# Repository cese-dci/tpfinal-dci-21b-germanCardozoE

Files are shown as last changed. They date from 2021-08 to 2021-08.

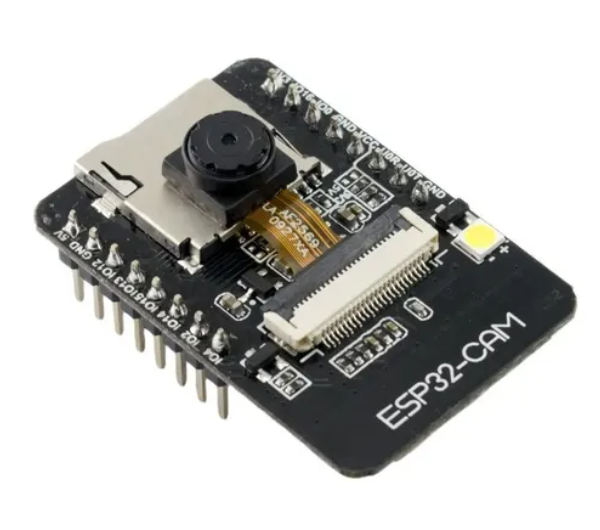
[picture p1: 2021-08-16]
doc/propuesta/esp32cam.png

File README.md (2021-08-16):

## Trabajo práctico final de la asignatura DCI ##
Este repositorio contiene el trabajo práctico final para la asignatura de Diseño de Circuitos Impresos de la carrera de posgrado de FIUBA.

* Autor: Cardozo Germán Eloy
* Título corto del trabajo:  ESP32-CAM
* Descripción:  El siguiente proyecto incluye tanto el circuito esquemático como el diseño del PCB realizado en kicad. A su vez se anexan diversas hojas de datos y bibliotecas utilizadas en su desarrollo.
ESP32-CAM es un módulo WiFi y Bluetooth que integra una pequeña cámara por lo que puede funcionar de manera independiente.
La camara OV2640 de 2MP integra un sensor de imagen CMOS UXGA (1632*1232) de 1/4 de pulgada. El pequeño tamaño del sensor y el bajo voltaje de operación brindan todas las características de una sola cámara UXGA y un procesador de imágenes. A través del control de bus SCCB, puede generar datos de imagen de 8/10 bits de varias resoluciones, como fotograma completo, submuestreo, zoom y ventanas.
La imagen UXGA de esta camara puede alcanzar hasta 15 cuadros por segundo (hasta 30 cuadros para SVGA y 60 cuadros para CIF). Los usuarios tienen un control completo sobre la calidad de la imagen, el formato de datos y la transmisión.
Todas las funciones de procesamiento de imágenes, incluida la curva gamma, el balance de blancos, el contraste, el croma, etc. se pueden programar a través de la interfaz SCCB.
Los sensores de imagen Omni Vision utilizan una tecnología de sensor única para mejorar la calidad de la imagen y reducir las imágenes en color nítidas y estables mediante la reducción o eliminación de defectos ópticos o electrónicos, como el ruido de patrón fijo, manchas y flotación.

## Principales Características ##
• Modelo: ESP32-CAM + Cámara OV2640
• Voltaje de Alimentación ESP 32 CAM: 5V
• Módulo Wi-Fi BT 802.11b/g/n
• Tipo de cámara: OV2640 2MP
• El modulo ESP 32CAM tiene CPU 32 bits de doble núcleo de baja potencia
• Frecuencia principal de hasta 240 MHz
• Potencia informática de hasta 600 DMIPS
• Velocidad de reloj de hasta 160 MHz
• Incorpora SRAM 520Kb, 4MPSRAM externa
• El modulo ESP-32 CAM Soporta interfaces: UART / SPI / I2C / PWM / ADC / DAC
• El modulo ESP-32-CAM Soporta cámaras OV2640 y OV7670, Flash Incorporado
• El modulo ESP 32-CAM Soporta tarjetas TF micro SD (Máximo 4 GB)
• El modulo ESP-32CAM Soporta la carga de imagen WiFi
• Compatible con modos de operación STA / AP / STA+AP
• Con antena PCB
• El modulo ESP32CAM integra conectores u.FL y FPC

## Licencia de este trabajo ##
Licencia GNU GPL

## Estructura del TP FINAL ##

Se propone y se pide utilizar la siguiente estructura.

* doc: Toda la información sobre el circuito, principalmente de autoría o procesamiento propio. Por ejemplo:
  * Notas de ingeniería propias.
  * Notas de aplicación propias.
  * Estudios previos, estado del arte, resumen de las investigaciones.
  * Notas con cálculos.
  * Dibujos adicionales.
  * Fotos de los prototipos.
  * Presupuestos, cotizaciones.
* info: Toda la iformación recolectada, principalmente de terceros, como por ejemplo:
  * Hojas de datos.
  * Notas de aplicación.
  * Info de productos comerciales.
  * Info en internet.
* pcb: Archivos de diseño esquemático y pcb.

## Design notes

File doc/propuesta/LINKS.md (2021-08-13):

## Links presentados ##

# imagenes #

[https://articulo.mercadolibre.com.ar/MLA-914001349-modulo-esp32-cam-camara-wifi-bluetooth-ov2640-2mp-arduino-_JM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]

# esquematico #

[https://randomnerdtutorials.com/esp32-cam-ai-thinker-pinout/]

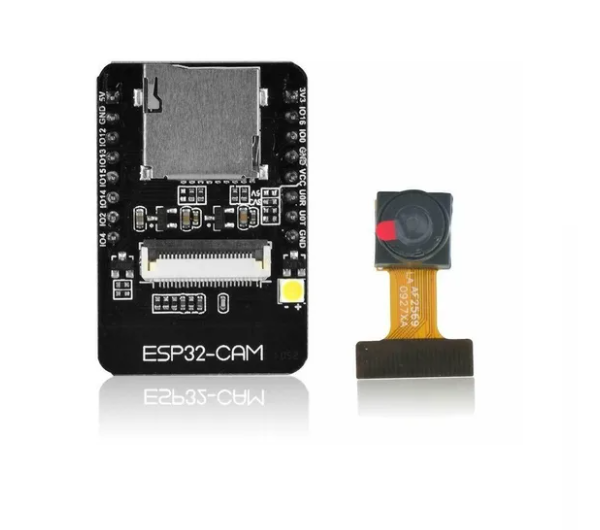
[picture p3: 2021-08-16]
doc/propuesta/esp32cam_superior.png

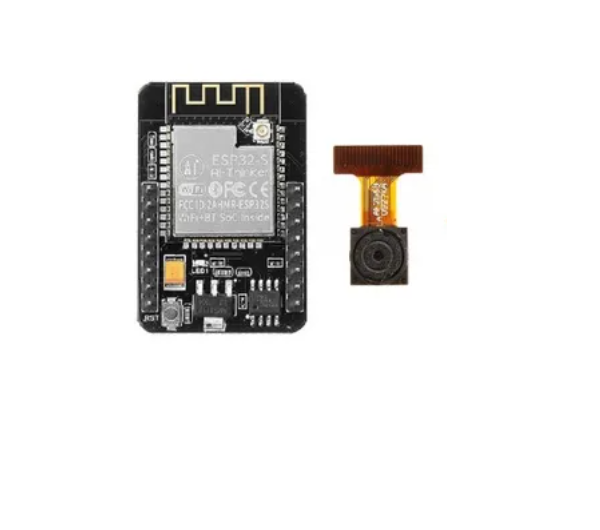
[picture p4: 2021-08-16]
doc/propuesta/esp32cam_inferior.png

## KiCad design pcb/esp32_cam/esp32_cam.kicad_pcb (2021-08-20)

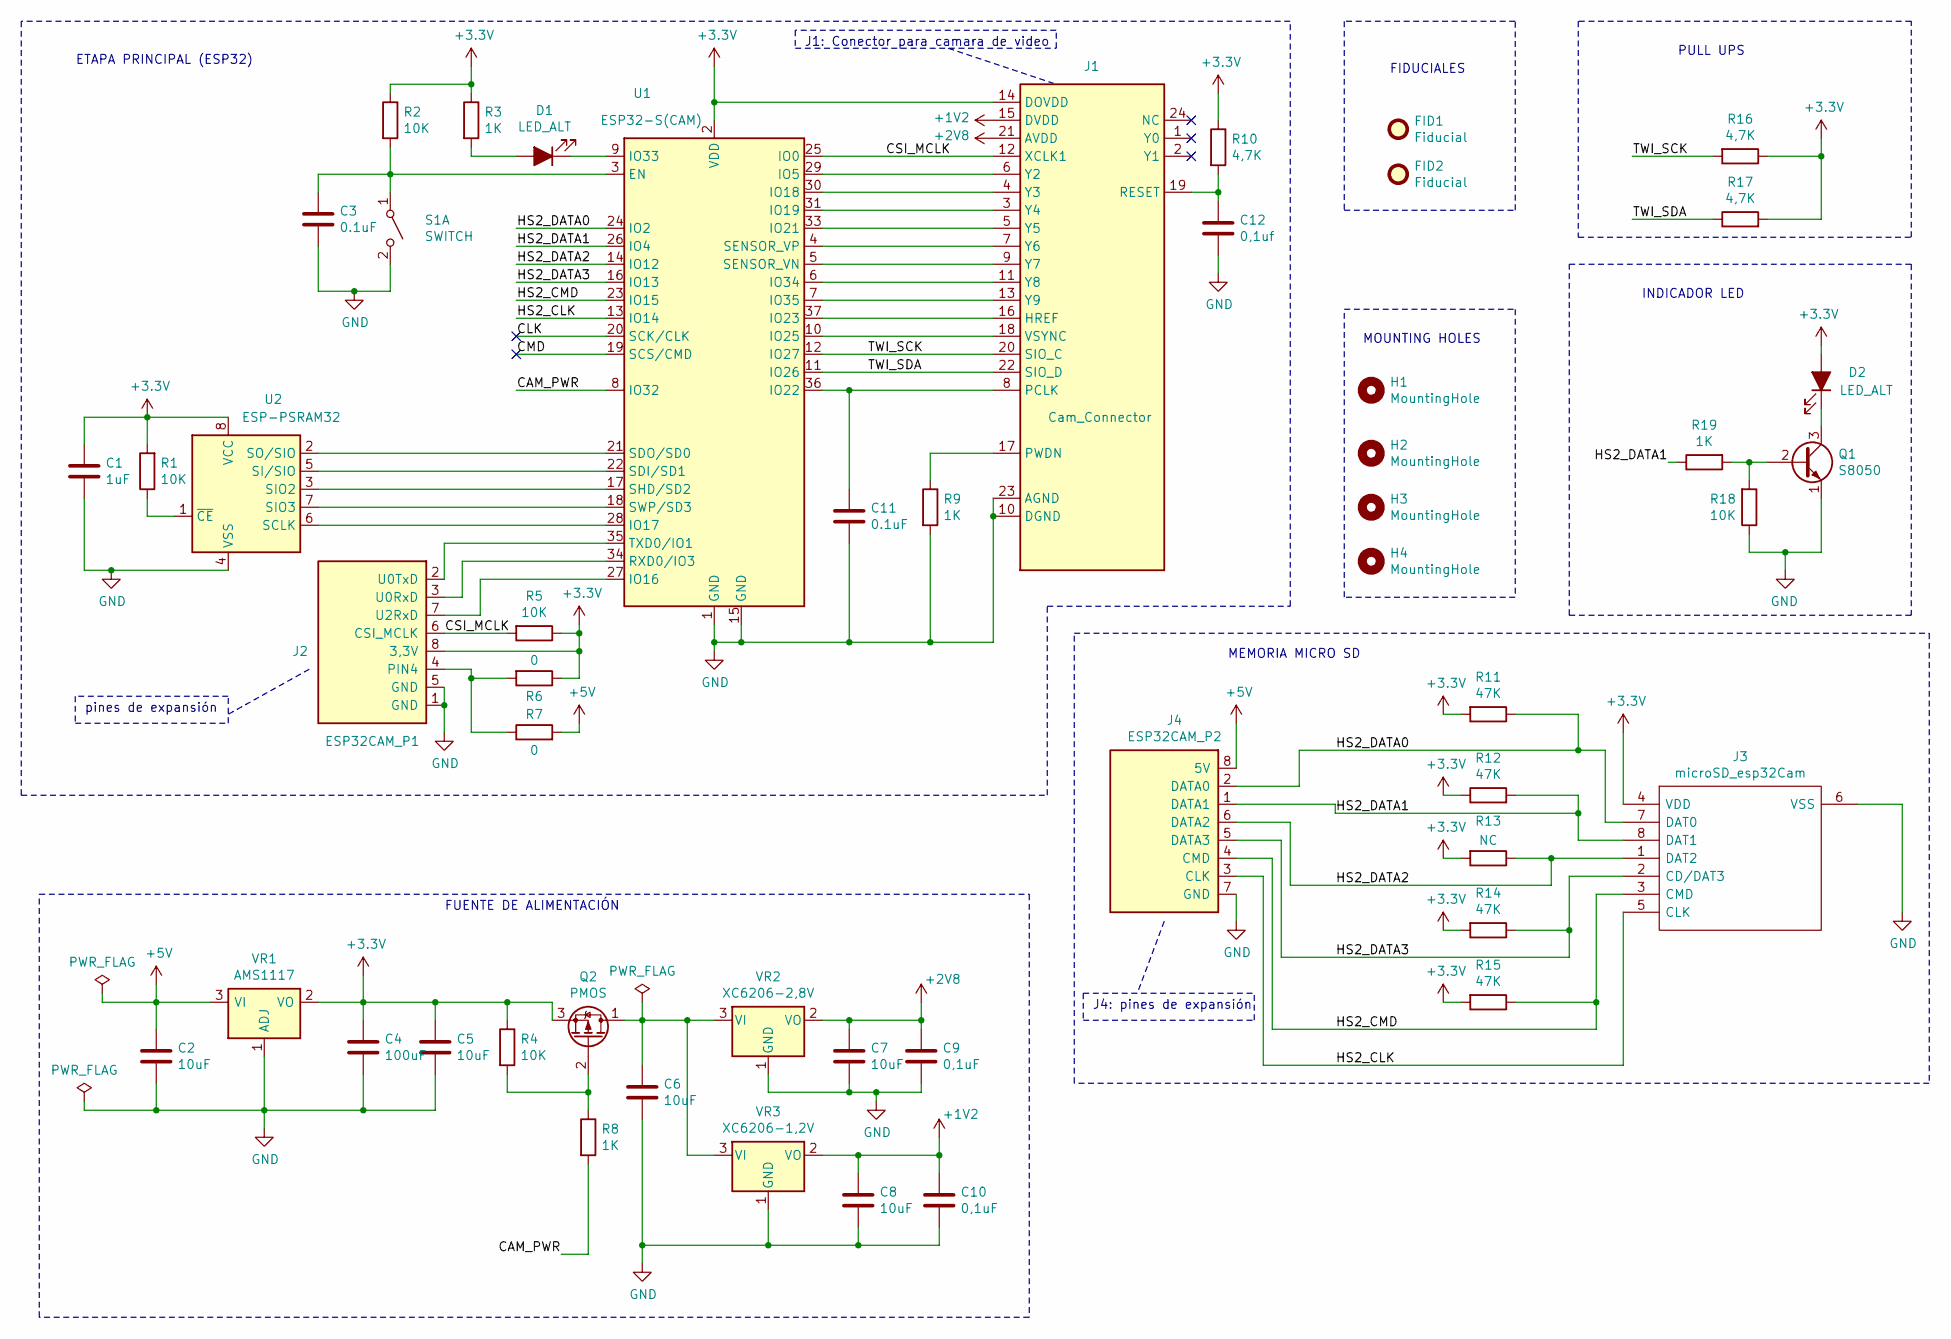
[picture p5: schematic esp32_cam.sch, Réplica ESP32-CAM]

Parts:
C1: 1uF; C_0805_2012Metric
C2, C5, C6, C7, C8: 10uF; C_0805_2012Metric
C3, C11: 0.1uF; C_0805_2012Metric
C4: 100uF; C_0805_2012Metric
C9, C10: 0,1uF; C_0805_2012Metric
C12: 0,1uf; C_0805_2012Metric
D1: LED_ALT; LED_1206_3216Metric_Pad1.42x1.75mm_HandSolder
D2: LED_ALT; LED_2816_7142Metric_Castellated
FID1, FID2: Fiducial; Fiducial_0.5mm_Mask1mm
H1, H2: MountingHole; MountingHole_2.5mm
H3, H4: MountingHole; MountingHole_2.1mm
J1: Cam_Connector; TE_2-1734839-4_1x24-1MP_P0.5mm_Horizontal
J2: ESP32CAM_P1; PinHeader_1x08_P2.54mm_Vertical
J3: microSD_esp32Cam; DM3ATSFPEJM5; Manufacturer_Part_Number DM3AT-SF-PEJM5; Mouser Part Number 798-DM3AT-SF-PEJM5
J4: ESP32CAM_P2; PinHeader_1x08_P2.54mm_Vertical
Q1: S8050; SOT-23
Q2: PMOS; SOT-23
R1, R2, R4, R5, R18: 10K; R_0805_2012Metric
R3, R8, R9, R19: 1K; R_0805_2012Metric
R6, R7: 0; R_0805_2012Metric
R10, R16, R17: 4,7K; R_0805_2012Metric
R11, R12, R14, R15: 47K; R_0805_2012Metric
R13: NC; R_0805_2012Metric
S1: SWITCH; SW_SPST_B3U-1000P
U1: ESP32-S(CAM); ESP32-WROOM-32U
U2: ESP-PSRAM32; SOIC-8_3.9x4.9mm_P1.27mm
VR1: AMS1117; SOT-223-3_TabPin2
VR2: XC6206-2,8V; SOT-23
VR3: XC6206-1,2V; SOT-23

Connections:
+1V2: C8.2, C10.2, J1.15 (DVDD), VR3.2 (VO)
+2V8: C7.2, C9.2, J1.21 (AVDD), VR2.2 (VO)
+3V3: C1.2, C4.2, C5.2, D2.2 (A), J1.14 (DOVDD), J2.8 (3,3V), J3.4 (VDD), Q2.3 (S), R1.2, R2.1, R3.1, R4.1, R5.1, R6.1, R10.1, R11.2, R12.1, R13.2, R14.2, R15.2, R16.1, R17.2, U1.2 (VDD), U2.8 (VCC), VR1.2 (VO)
+5V: C2.2, J4.8 (5V), R7.2, VR1.3 (VI)
/CAM_PWR: R8.2, U1.8 (IO32)
/CLK: U1.20 (SCK/CLK)
/CMD: U1.19 (SCS/CMD)
/CSI_MCLK: J1.12 (XCLK1), J2.6 (CSI_MCLK), R5.2, U1.25 (IO0)
/HS2_CLK: J3.5 (CLK), J4.3 (CLK), U1.13 (IO14)
/HS2_CMD: J3.3 (CMD), J4.4 (CMD), R15.1, U1.23 (IO15)
/HS2_DATA0: J3.7 (DAT0), J4.2 (DATA0), R11.1, U1.24 (IO2)
/HS2_DATA1: J3.8 (DAT1), J4.1 (DATA1), R12.2, R19.1, U1.26 (IO4)
/HS2_DATA2: J3.1 (DAT2), J4.6 (DATA2), R13.1, U1.14 (IO12)
/HS2_DATA3: J3.2 (CD/DAT3), J4.5 (DATA3), R14.1, U1.16 (IO13)
/TWI_SCK: J1.20 (SIO_C), R16.2, U1.12 (IO27)
/TWI_SDA: J1.22 (SIO_D), R17.1, U1.11 (IO26)
GND: C1.1, C2.1, C3.1, C4.1, C5.1, C6.1, C7.1, C8.1, C9.1, C10.1, C11.2, C12.2, J1.10 (DGND), J1.23 (AGND), J2.1 (GND), J2.5 (GND), J3.6 (VSS), J4.7 (GND), Q1.1 (E), R9.2, R18.1, S1.2 (B), U1.1 (GND), U1.15 (GND), U1.38 (GND), U1.39 (GND), U2.4 (VSS), VR1.1 (ADJ), VR2.1 (GND), VR3.1 (GND)
unnamed: C3.2, R2.2, S1.1 (A), U1.3 (EN)
unnamed: C6.2, Q2.1 (D), VR2.3 (VI), VR3.3 (VI)
unnamed: C11.1, J1.8 (PCLK), U1.36 (IO22)
unnamed: C12.1, J1.19 (RESET), R10.2
unnamed: D1.1 (K), U1.9 (IO33)
unnamed: D1.2 (A), R3.2
unnamed: D2.1 (K), Q1.3 (C)
unnamed: J1.3 (Y4), U1.31 (IO19)
unnamed: J1.4 (Y3), U1.30 (IO18)
unnamed: J1.5 (Y5), U1.33 (IO21)
unnamed: J1.6 (Y2), U1.29 (IO5)
unnamed: J1.7 (Y6), U1.4 (SENSOR_VP)
unnamed: J1.9 (Y7), U1.5 (SENSOR_VN)
unnamed: J1.11 (Y8), U1.6 (IO34)
unnamed: J1.13 (Y9), U1.7 (IO35)
unnamed: J1.16 (HREF), U1.37 (IO23)
unnamed: J1.17 (PWDN), R9.1
unnamed: J1.18 (VSYNC), U1.10 (IO25)
unnamed: J2.2 (U0TxD), U1.35 (TXD0/IO1)
unnamed: J2.3 (U0RxD), U1.34 (RXD0/IO3)
unnamed: J2.4 (PIN4), R6.2, R7.1
unnamed: J2.7 (U2RxD), U1.27 (IO16)
unnamed: Q1.2 (B), R18.2, R19.2
unnamed: Q2.2 (G), R4.2, R8.1
unnamed: R1.1, U2.1 (~CE)
unnamed: U1.17 (SHD/SD2), U2.3 (SIO2)
unnamed: U1.18 (SWP/SD3), U2.7 (SIO3)
unnamed: U1.21 (SDO/SD0), U2.2 (SO/SIO)
unnamed: U1.22 (SDI/SD1), U2.5 (SI/SIO)
unnamed: U1.28 (IO17), U2.6 (SCLK)

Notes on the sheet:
PULL UPS
INDICADOR LED
FUENTE DE ALIMENTACIÓN
MEMORIA MICRO SD
MOUNTING HOLES
ETAPA PRINCIPAL (ESP32)
FIDUCIALES
J1: Conector para camara de video
J4: pines de expansión
pines de expansión

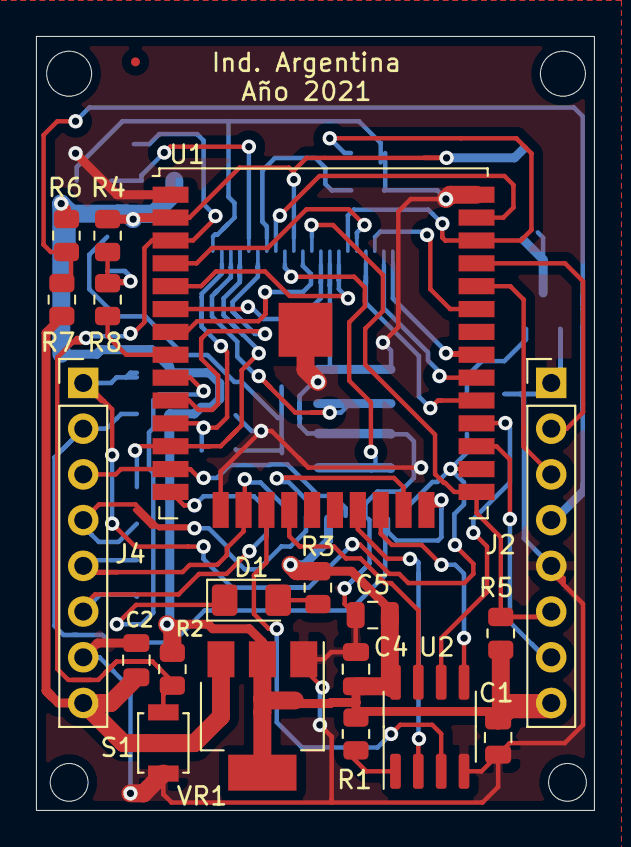
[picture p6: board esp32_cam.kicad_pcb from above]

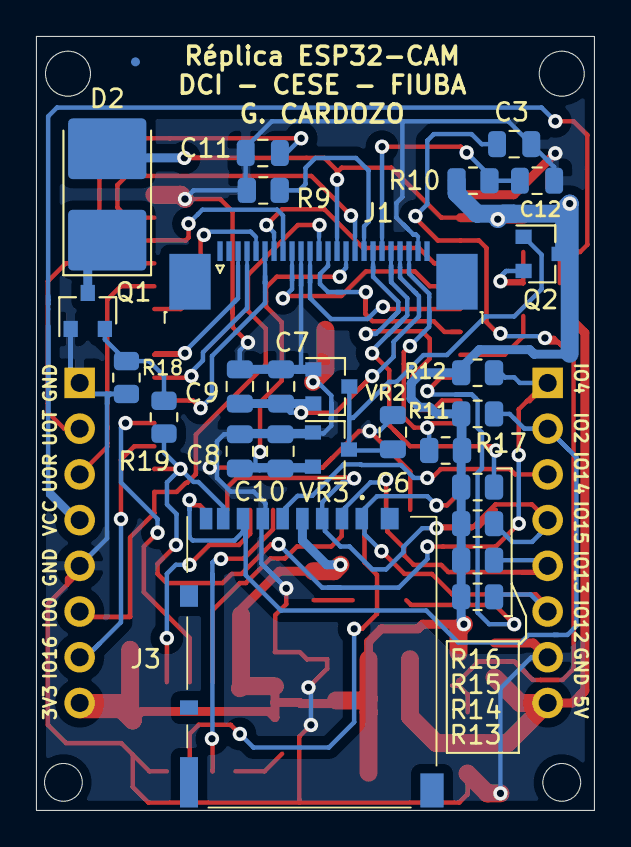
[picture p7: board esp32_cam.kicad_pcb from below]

Board: 2 copper layers, 31.0 x 43.0 mm, 51 parts (27 on the bottom side), 45 nets.

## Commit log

2021-08-09 carga de esquematico completo
    [esp32_cam.kicad_pcb, esp32_cam.sch]
2021-08-13 correcciones de esquematico y se agrega y completa información
    [esp32_cam.kicad_pcb, esp32_cam.sch]
2021-08-14 se sube primera versión del PCB
    [esp32_cam.kicad_pcb, esp32_cam.sch]
2021-08-16 se sube versión final y se agrega documentación
    [esp32_cam.kicad_pcb, esp32_cam.sch, esp32_cam2.kicad_pcb]
2021-08-16 se corrige el README principal
2021-08-16 se agrega introducción del modulo ESP32-CAM
2021-08-16 se corrige serigrafía
    [esp32_cam.kicad_pcb]
2021-08-17 se crea la carpeta shapes3D
    [esp32_cam.kicad_pcb, esp32_cam.sch]
2021-08-20 se amplia el clearence de 0.2 0.25
    [esp32_cam.kicad_pcb, esp32_cam2.kicad_pcb]
